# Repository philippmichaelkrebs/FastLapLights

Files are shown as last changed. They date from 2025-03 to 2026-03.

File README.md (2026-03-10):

# FastLapLights

**"Gentlemen, start your engines!"** 🏁  

Bring FIA-style lighting to your slot car track with FastLapLights - a high-tech lighting and telemetry system for Carrera Digital tracks! 
Control WS2812b Start Lights, Pit Lane Lights and Track Flags with stunning LED animations that bring your races to life. Want more? FastLapLights als taps into the real-time data stream from the Carrera Control Unit, filters the most relevant messages, and outputs the via UART - perfect for powering external displays, mechanical 7-segment scoring pylons, or even fuel and pit-stop management systems. 
With support for 3.3V and 5V output, you've got everything you need to bring custom hardware into the mix.
Whether you're racing for fun or building the ultimate home track, FastLapLights adds a whole new level of immersion, control and creativity.

Following Models are supported:
- Carrera Digital 124
- Carrera Digital 132

Preview:  
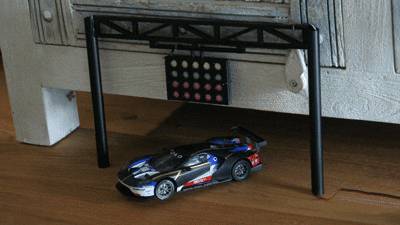
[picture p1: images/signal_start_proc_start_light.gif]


# Features

## Start Lights
Perfect race countdown sequence with WS2812B LEDs 🚦

You can switch between horizontal and vertical alignment for the start lights WS2812B led strips. Vertical alignment requires more soldering but looks more realistic, giving you the option to physically seperate the  lights - just like in real motorsport.
The system is designed to handle 40 leds. So both the front and the back of the lights illuminated. You nearly have a 360 degree visibility of the start lights.

## Pit Lane Lights
Manage pit stops like a real motorsport pro!

Instead of start loghts, you can choose to illuminate pit lane lights. This is an either-or option - controlled via a solder bridge on the back of the pcb. Simpy close the appropriate bridge to switch the functionality.

## Track Flag System
RGB LEDs indicate race conditions (Green, Yellow, Red) 🚥

With a red and green led, you can animate track lights. It's also possible to use a rgb led with r and g connected only. Race status indicated by flags:
- Green: go, 
- Yellow: caution, 
- Red: stop
If you plan to use multiple RGB LEDs, you should use a mosfet to avoid overloading the uCs GPIOs.

## Real-Time Data Capture
Tap into live control unit telemetry!

The STM32 continuously processes data from the Carrera Control Unit. A filtered stream of the most relevant messages is available via the UART interface. This gives you a powerful foundation to build custom applications and add unique behavior to your racetrack setup. 
Whether it's a mechanical 7-segment scoring pylon or a smart pit stop prediction system, FastLapLights gives your cicuit the edge it deserves.

# Get Started

- Order the microcontroller from jlcpcb (see section documentation)
- Flash the firmware on your STM32 microcontroller (see section documentation)
- Connect WS2812B & RGB LEDs according to the purpose.
- Solder power wires to the track
- Power up & lights out!

# Pinouts
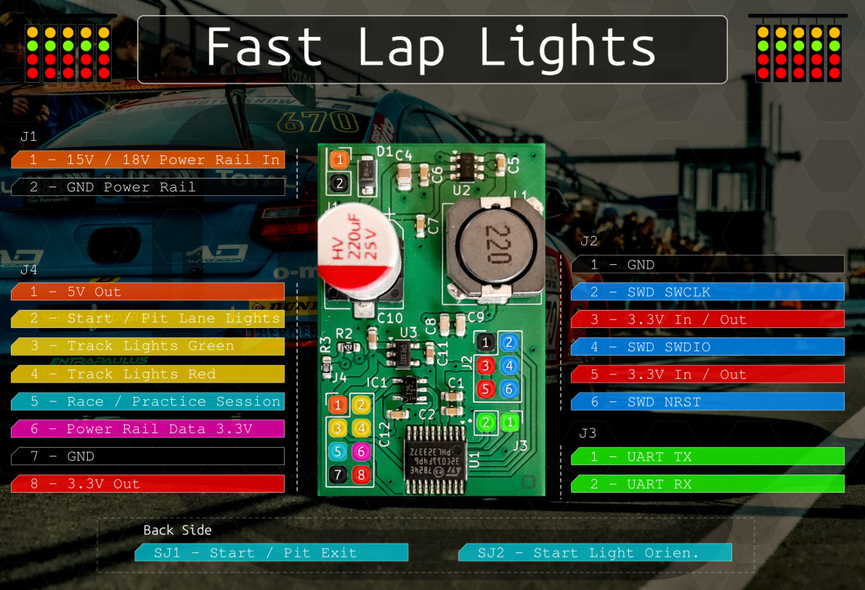
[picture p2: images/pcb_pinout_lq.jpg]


# UART
The data that is transmitted by the Control Unit is an asynchronous serial protocol. The chunks are of various size. Notably, the protocol doesn't use a traditional stop bit. The cu transmits data in a structured, continouos stream every 75 milli secs. Each transmission cycle contains 10 distinct messages sent in a strict and predictable sequence.

The controller processes this incomimg data and outputs it via UART, using a **32-byte single-buffered TX DMA system**. Each UART transmission contains a snapshot of the current race state. TX only, RX is disabled.

## UART Configuration
- Baud rate: 115200
- Data format: 8 data bits, no parity, 1 stop bit (8N1)
## Application Behavior
- Message Size: Each UART message is exactly 32 bytes in length.
- Contents: The message includes all relevant application data (e.g., race state, positions, fuel levels, etc.) and is a snapshot of the current race state.
- Transmission Rate: A new message is transmitted every 750 milliseconds.

|Byte Index|Field|Description|
|---|---|---|
|{0,4,...}|`Driver X - Fuel`|Remaining fuel of Driver 0–5|
|{1,5,...}|`Driver X - Position`|Current position of Driver 0–5|
|{2,6,...}|`Driver X - Finished`|Driver 0–5 has finished the race (1 = finished)|
|{3,7,...}|`Driver X - Laps`|Laps completed by Driver 0–5|
|24|`Fastest Lap`|Driver index with the fastest lap (0–5, or 0xFF if none)|
|25|`Start Lights Count`|Number of red lights currently lit|
|26|`Lap Count`|Total laps completed by the leader|
|27|`Reset Event`|Non-zero if a global reset has occurred|
|28|`Race State`|Current state of the race (see `RaceState` enum)|
|29|`Session Type`|Race or Qualifying session (see `SessionType` enum)|
|30 & 31|`Track Time`|16-bit track time counter, synced with track (13.33 Hz)|

## Message Decoding Example

The following C code snippet demonstrates how to decode the message and populate internal state structures:
```c 
typedef enum {
	RACE,
	QUALIFYING_TRAINING
}S essionType;

typedef enum {
	RACE_STATE_STARTUP,
	RACE_STATE_RED_FLAG,
	RACE_STATE_YELLOW_FLAG,
	RACE_STATE_GREEN_FLAG,
	RACE_STATE_START_PROC,
	RACE_STATE_JUMP_START,
	RACE_STATE_OPEN
} RaceState;

typedef struct {
	uint8_t fuel;
	uint8_t position;
	uint8_t finished;
	uint8_t laps;
} DriverData;

typedef struct {
	DriverData 	      driver_data[6];
	uint8_t		fastest_lap_driver;
	uint8_t		start_lights;
	uint8_t		lap_count;
	uint8_t		lap_count_nibble_completed;
	uint8_t		reset_event;
	RaceState	      race_state;
	SessionType	      session_type;
} RaceInfo;

// Global structure updated via UART
volatile RaceInfo	uart_race_info = {
		.driver_data = {
			{ .fuel = 0, .position = 0, .finished = 0, .laps = 0 },
			{ .fuel = 0, .position = 0, .finished = 0, .laps = 0 },
			{ .fuel = 0, .position = 0, .finished = 0, .laps = 0 },
			{ .fuel = 0, .position = 0, .finished = 0, .laps = 0 },
			{ .fuel = 0, .position = 0, .finished = 0, .laps = 0 },
			{ .fuel = 0, .position = 0, .finished = 0, .laps = 0 }
		},
		.fastest_lap_driver = 0xFF,       // 0xFF no fastest lap yet
		.start_lights = 0,
		.lap_count = 0,
		.reset_event = 0,
		.race_state = RACE_STATE_STARTUP,
		.session_type = RACE
	};
	
volatile uint8_t rx_buf[32];

void uart_interrupt(void){
	uint8_t buf_idx = 0;
	for (uint8_t _driver = 0; _driver < 6; _driver++){
		uart_race_info.driver_data[_driver].position = 
			rx_buf[buf_idx++];
		uart_race_info.driver_data[_driver].fuel = 
			rx_buf[buf_idx++];
		uart_race_info.driver_data[_driver].laps = 
			rx_buf[buf_idx++];
		uart_race_info.driver_data[_driver].finished = 
			rx_buf[buf_idx++];
	}

	uart_race_info.fastest_lap_driver = rx_buf[buf_idx++];
	uart_race_info.start_lights = rx_buf[buf_idx++];
	uart_race_info.lap_count = rx_buf[buf_idx++];
	uart_race_info.reset_event = rx_buf[buf_idx++];
	uart_race_info.race_state = (RaceState)rx_buf[buf_idx++];
	uart_race_info.session_type = (SessionType)rx_buf[buf_idx++];

	track_time = 0xFF00 & (rx_buf[buf_idx++] << 8);
	track_time |= rx_buf[buf_idx++];
}
```

# Documentation
- [How the Lights Work](/docs/how_the_lights_work.md)
- [Getting Started](/docs/getting_started.md)

# Contribute & Support

Got ideas? Found a bug? Want to make it even cooler? 
Open an issue, submit a PR, or just say hi!

Developer: Philipp Krebs  
Contact: pmge.krebs@gmail.com  
Repo: https://github.com/philippmichaelkrebs

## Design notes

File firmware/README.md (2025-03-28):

# Overview
The system decodes Manchester-encoded data from the power line and categorizes messages based on their content. Once a new message is available, it is stored in a FIFO buffer, and the interrupt pin is set HIGH. The I2C master can then request the stored data. The relevant messages occus at round about 13Hz.

# Data Handling & Communication
## Manchester Code Decoding
The system continuously decodes Manchester-encoded data from the track’s power line.
Messages are categorized into predefined patterns for easy processing.

## FIFO Buffer & Interrupts
New data is stored in a FIFO buffer. When new messages arrive, the interrupt pin is set HIGH to signal the presence of new data.
Via I2C request a message from the FIFO. The system responds with the latest available data. The interrupt pin is cleared once the FIFO is read.

# Data Message Structure
Each data chunk is 16 bits (2 bytes) long and consists of an identifier and a value:
Bits    Field   Description
15-8    Identifier  Defines the type of message (e.g., car status, system events)
7-0 Value   Stores specific data related to the identifier (e.g., speed, lap time)

## Message Types & Decoding

The identifier (high byte) determines the type of data, while the value (low byte) contains specific information.
### Car-Related Messages
| Identifier (Hex)  | Description |
|---:|-----|
| 0xFF0Z |  Car with ID Z finishes the race |
| 0xFEXZ |  Car with ID Z crosses the lap counter; if X = 1, it records a new fastest lap |
| 0xFDXZ |  Speed of car Z, where Z is a 4-bit car ID, and X is a 12-bit speed value |
| 0xFCXZ |  Fuel level of car Z (X is a 3-bit integer fuel value) |
| 0xFBXZ |  Throttle position of car Z |
| 0xFA0Z |  Car Z jumped the start |
### System Messages
| Identifier (Hex)  | Description |
|---:|-----|
| 0xAA0X |  Number of start lights illuminated (X = 0 to 5) |
| 0xAB0X | Yellow flag (X = 1 yellow flag, X = 0 yellow flag withdrawn |
| 0x0001 |  Total system reset |
| 0x0002 |  Reset position and lap counter |

## Example Data Transactions
### Example 1: Car 3 Finishes the Race
Raw Message: 0xFF03
Decoded:

    Identifier: 0xFF → Car finishes race. 
    Car ID: 03 
    Description: Car 3 finished the race.

### Example 2: Start lights changed
Raw Message: 0xAA03
Decoded:
    
    Identifier: 0xAA → Start lights changed
    Value: 3
    3 red lights lit at the start light

# Notes & Considerations
The interrupt pin remains HIGH until the FIFO is read.

# Contribute & Support

Got ideas? Found a bug? Want to make it even cooler? 
Open an issue, submit a PR, or just say hi!

    Developer: Philipp Krebs 
    Contact: pmge.krebs@gmail.com 
    Repo: https://github.com/philippmichaelkrebs

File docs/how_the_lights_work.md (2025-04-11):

# 🏁 How the Lights Work

## 📘 Introduction to FIA Light Signals

The FIA (Fédération Internationale de l'Automobile) defines several key light systems in their [recommendations for motor racing](https://argent.fia.com/web/fia-public.nsf/1330F0769A59327AC125736200478FB9/$FILE/03__Recommended_light_signals.pdf). These signals help ensure safety and structure during a race. Here's a simplified breakdown:

- **Start Light System**
  - Indicates the track status: open, closed, or released
  - Controls the start procedure
  - Signals a jump start or aborted start

- **Pit Lane Lights**
  - Indicates whether the pit lane is open or closed

- **Track Light Signals**
  - **Yellow flag**: caution, danger ahead
  - **Red flag**: race is stopped or paused
  - **Green flag**: track is clear and race continues

These are the most relevant signals for our slot car adaptation.

---

## 🟥 Red Flag – Race Pause

In FIA terms, a red flag means race stoppage. For us slot car/Carrera fans, it’s more like a **race pause**. All cars stop immediately — often because a car flies off the track and needs rescue. This can happen:

- **Before the start procedure begins**, or
- **Mid-race**, due to track incidents

The control unit sends a **reset** followed by a **5x red light** signal. If the previous state wasn't a start sequence, it's treated as a red flag.

### Light Behavior

- **Start Light**: All red lights ON. Yellow and green OFF.  
- **Pit Lane**: Red light ON – pit lane is closed.  
- **Track Lights**: All lights RED – red flag signal.

### How The Start Light Looks
 


### How The Track Light Looks
 


---

## 🟨 Yellow Flag / Safety Car Phase

A yellow flag indicates caution on the track – there's an incident or obstacle. You can optionally deploy a **safety car**. Without one, drivers are simply advised to slow down (though that's more a gentleman’s agreement than a rule 😉).

You trigger this phase by pressing the **Safety Car button**.

### Light Behavior

- **Start Light**: Yellow lights BLINK at 5 Hz.  
- **Pit Lane**: Green light ON – pit lane is open.  
- **Track Lights**: Yellow lights BLINK at 5 Hz.

### How The Start Light Looks
 


### How The Track Light Looks
 


---

## 🟩 Green Flag – Race Resumes

A green flag means the track is clear and the race is back on.

There’s **no direct button** to start a green flag phase. Instead, it's shown **automatically for 10 seconds** after ending a red flag or yellow flag phase.

### Light Behavior

- **Start Light**: Green lights BLINK at 1 Hz (for 10 seconds).  
- **Pit Lane**: Green light ON – track and pit lane are open.  
- **Track Lights**: Green lights BLINK at 1 Hz – track is clear.

---

## 🚦 Start Procedure

Pressing the **Start button** during a red flag triggers the official **start sequence**. According to FIA rules, only the **start light system** is active during this sequence — track lights remain off, assuming the track is already clear.

### Light Behavior

- **Start Light**: Red lights turn on in sequence (typical countdown).  
- **Pit Lane**: Red light ON during countdown; turns green at race start.  
- **Track Lights**: All OFF – the track is considered ready.

### How The Start Light Looks
 


---

## 🚫 Jump Start

If a car jumps the start by hitting the throttle before the lights go out, it’s a **jump start**. In slot car logic, this acts like a **start abort**. So we follow the FIA approach:

### Light Behavior

- **Start Light**: Red lights stay ON; Yellow lights FLASH at 1 Hz.  
- **Pit Lane**: Red light ON – pit lane closed.  
- **Track Lights**: All OFF – track assumed clear.

### How The Start Light Looks
 


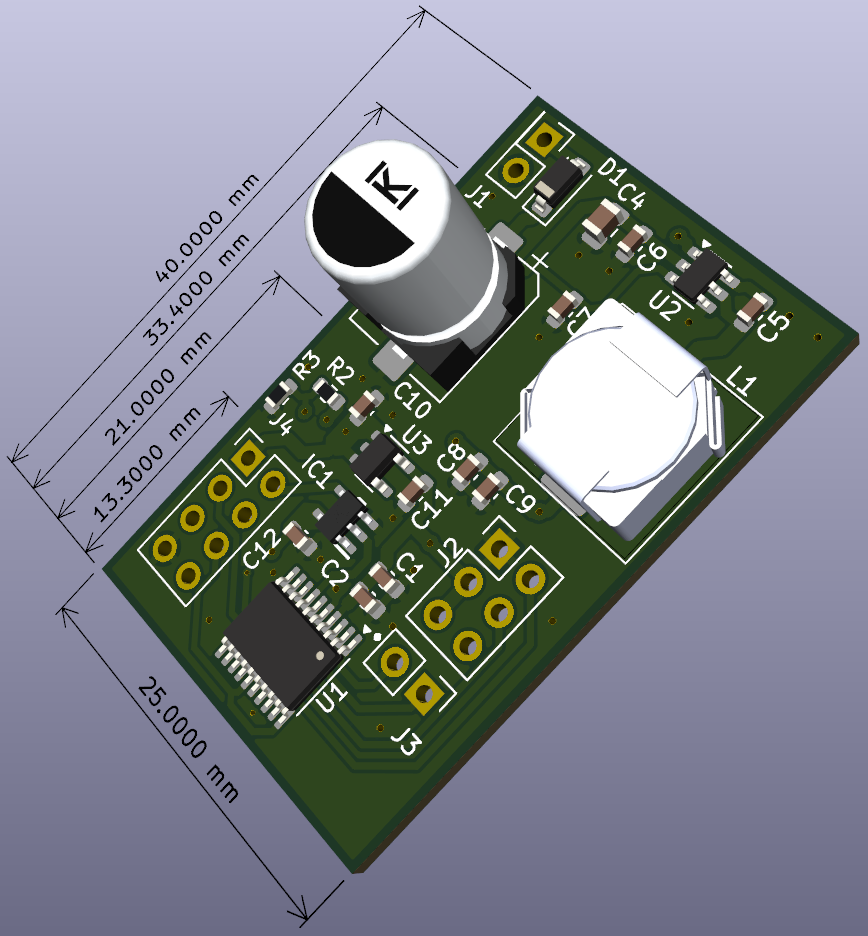
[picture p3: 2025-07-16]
images/FastLapLightsMK7.png

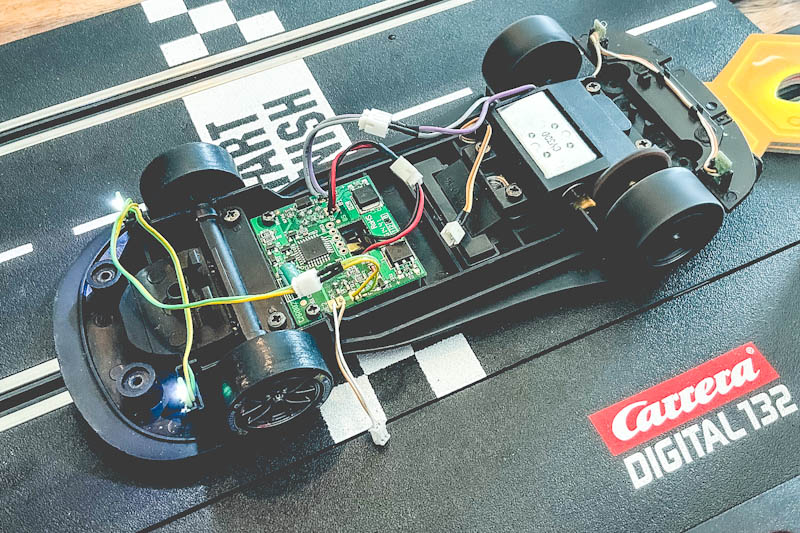
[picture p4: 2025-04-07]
images/protocol_reverse_engineering.jpg

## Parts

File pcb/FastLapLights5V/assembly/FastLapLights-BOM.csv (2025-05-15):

Designator | Comment | Footprint | LCSC
C1,C10,C11 | 4.7uF | Capacitor_SMD:C_0603_1608Metric | C1705
C2,C5,C6,C7,C12 | 0.1uF | Capacitor_SMD:C_0603_1608Metric | C1591
C3 | 220uF | Library:CP_220_Honor_Elec_HV1E227M0810PZ | C5246542
C4 | 22uF | Capacitor_SMD:C_0805_2012Metric | C602037
C8,C9 | 22uF | Capacitor_SMD:C_0603_1608Metric | C86295
D1 | MBR0540 | Diode_SMD:D_SOD-123 | C236080
IC1 | 74HCT1G125GV,125 | Library:SOT95P275X110-5N | C12502
L1 | 22uH | Library:L_SXN_SMDRH104R-220MT | C72414
R2 | 4k7 | Resistor_SMD:R_0603_1608Metric | C99782
R3 | 1k | Resistor_SMD:R_0603_1608Metric | C22548
U1 | STM32C011F4Px | Package_SO:TSSOP-20_4.4x6.5mm_P0.65mm | C5452432
U2 | AP63205WU | Package_TO_SOT_SMD:TSOT-23-6 | C2071056
U3 | AP2112K-3.3 | Package_TO_SOT_SMD:SOT-23-5 | C3021085

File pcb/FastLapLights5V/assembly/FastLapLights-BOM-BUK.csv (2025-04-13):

Designator | Comment | Footprint | LCSC
C1 | 4.7uF | Capacitor_SMD:C_0603_1608Metric | C1705
C2 | 0.1uF | Capacitor_SMD:C_0603_1608Metric | C1591
C3 | 100uF | Library:CP_Elec_A768KS227M1VLAE024 | C3274444
C4 | 22uF | Capacitor_SMD:C_0805_2012Metric | C602037
C5 | 100nF | Capacitor_SMD:C_0805_2012Metric | C519981
C6 | 0.1uF | Capacitor_SMD:C_0805_2012Metric | C519981
C7 | 4.7uF | Capacitor_SMD:C_0603_1608Metric | C1705
C8 | 4.7uF | Capacitor_SMD:C_0603_1608Metric | C1705
C9 | 0.1uF | Capacitor_SMD:C_0805_2012Metric | C519981
C10 | 22uF | Capacitor_SMD:C_0603_1608Metric | C86295
C11 | 22uF | Capacitor_SMD:C_0603_1608Metric | C86295
C12 | 0.1uF | Capacitor_SMD:C_0805_2012Metric | C519981
C13 | 22uF | Capacitor_SMD:C_0603_1608Metric | C86295
C14 | 0.1uF | Capacitor_SMD:C_0603_1608Metric | C1591
D1 | MBR0540 | Diode_SMD:D_SOD-123 | C236080
IC1 | 74HCT1G125GV,125 | Library:SOT95P275X110-5N | C12502
L1 | 22.8uH | Library:L_EATON_DR1030-220-R | C2638823
R1 | 4k7 | Resistor_SMD:R_0603_1608Metric | C99782
R2 | 4k7 | Resistor_SMD:R_0603_1608Metric | C99782
R3 | 1k | Resistor_SMD:R_0603_1608Metric | C22548
U1 | STM32C011F4Px | Package_SO:TSSOP-20_4.4x6.5mm_P0.65mm | C5452432
U2 | AP63205WU | Package_TO_SOT_SMD:TSOT-23-6 | C2071056
U3 | AP2112K-3.3 | Package_TO_SOT_SMD:SOT-23-5 | C51118
U4 | BD33FC0FP | Package_TO_SOT_SMD:TO-252-2 | C2846670

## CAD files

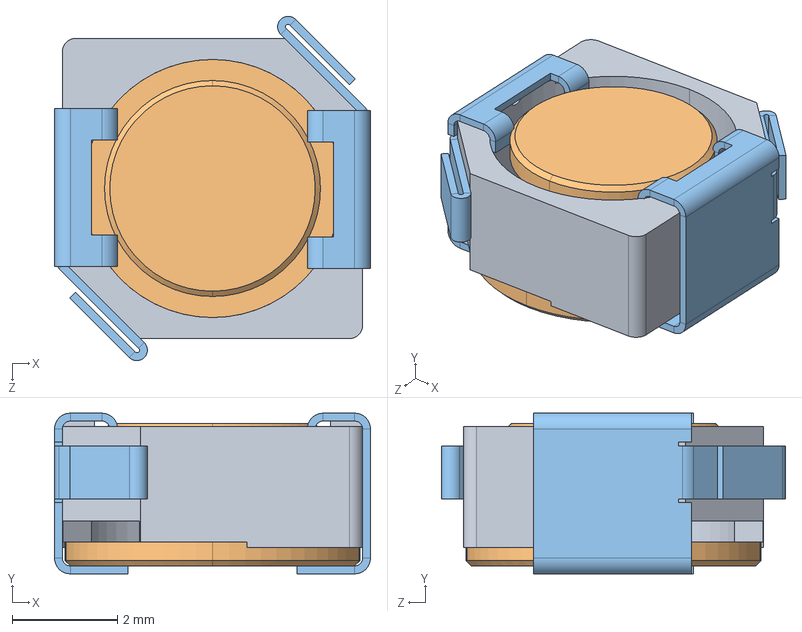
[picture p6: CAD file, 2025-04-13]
pcb/FastLapLights5V/3D/DR1030-220-R.stp
6.00 x 3.05 x 6.54 mm

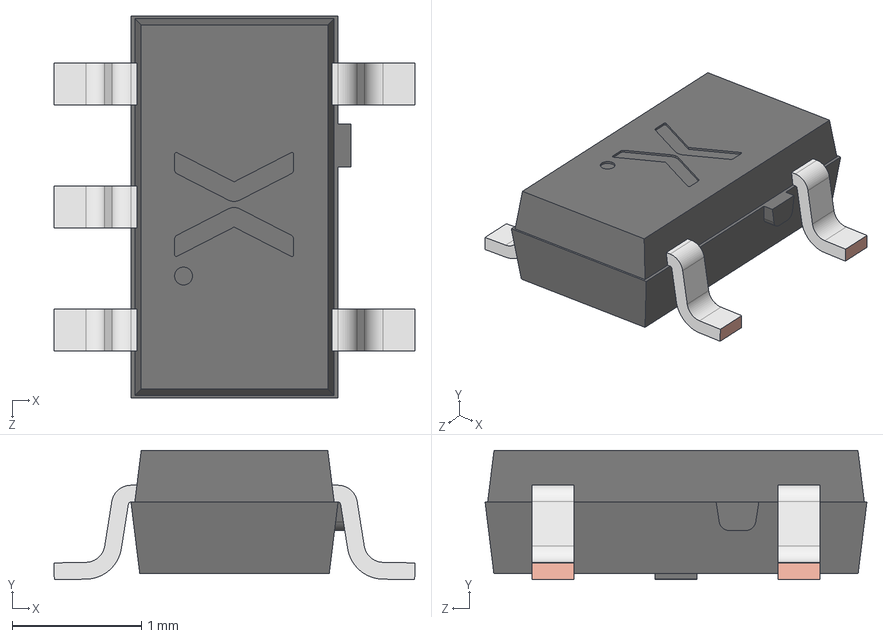
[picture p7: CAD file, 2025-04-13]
pcb/FastLapLights5V/3D/74HCT1G125GV,125.stp
2.79 x 1.00 x 2.95 mm
SOT753 Lower mold body
SOT753 Lead x 5
SOT753 Upper mold body

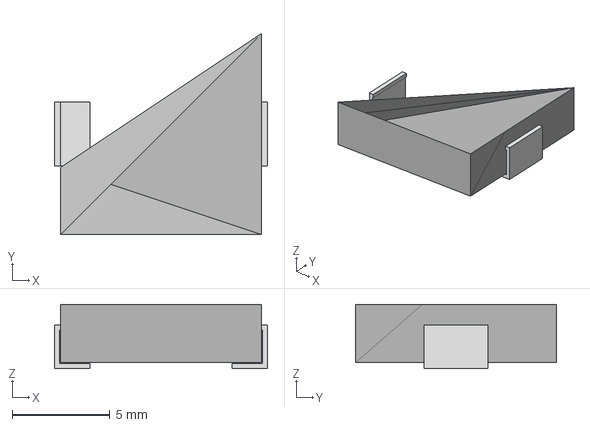
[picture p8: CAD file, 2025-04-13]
pcb/FastLapLights5V/3D/DR1030.step
10.9 x 10.3 x 3.30 mm

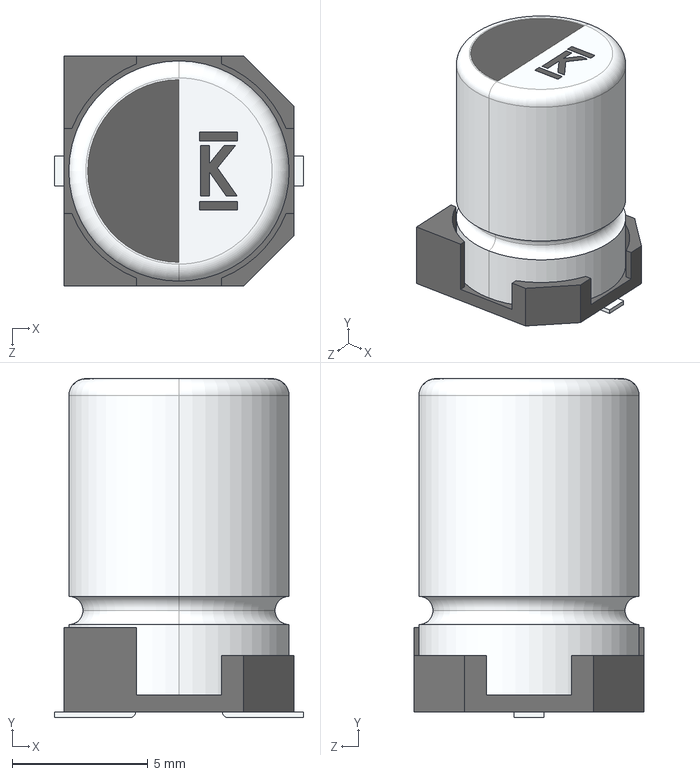
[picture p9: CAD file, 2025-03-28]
pcb/FastLapLights5V/3D/A768KS227M1VLAE024.step
9.20 x 12.5 x 8.50 mm

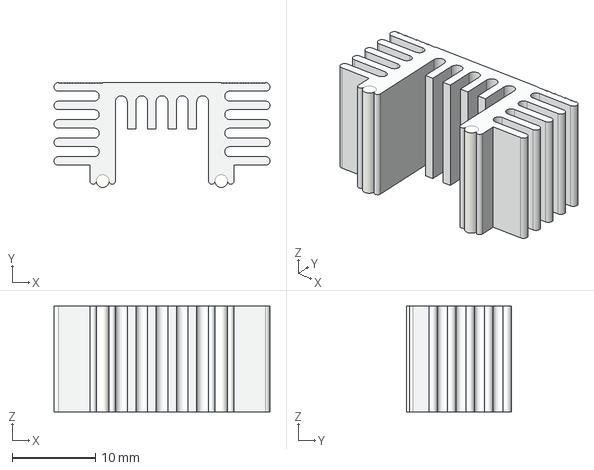
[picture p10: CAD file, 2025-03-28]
pcb/FastLapLights5V/3D/DV-T263-201E-TR.stp
25.9 x 12.6 x 12.7 mm

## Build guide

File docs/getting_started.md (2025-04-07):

# 🏎️ FastLapLight – FIA Style Lights for Slot Car Racing

Bring high-speed realism to your slot car track with FastLapLight – a customizable lighting system that emulates real FIA race lights for start sequences, pit lane, and track sectors.

## What You Need

    - Access to this repository
    - PCB from JLCPCB (with assembly option)
    - WS2812B LED strip (60 LEDs/m)
    - 5mm RGB LEDs (for track lights)
    - 3D printer for enclosures (STL files included)
    - Basic soldering tools and wire

## Step-by-Step Setup
### 1. Clone the Repo via: 
 
git clone https://github.com/philippmichaelkrebs/FastLapLights.git

    - Make sure to clone all files, including the STL and assembly folders.
    - Alternativly download the repository as zip.

### 2. Order PCB from JLCPCB

- Go to jlcpcb.com
- Upload the Gerber files located in the /pcb folder
- Select Assembly option
- Upload the required BOM and Pick & Place files from /assembly

Once the PCB arrives, all surface-mounted components will already be placed for you.

### 3. Print the Enclosures

    Navigate to the STL/ folder

    Choose the appropriate housing:
    
        - generic_light_base.stl
        - starting_light_jib.stl
        - starting_light_faceplate.stl
        - pit_lane_light.stl

    Use your favorite slicer and print using black PLA or ABS for best realism

### 4. Choose Your Light Setup

 | Light Type   | LED Type |    LED Count |
 | -------------|----------|--------------|
|Starting Light |WS2812B (60/m)|    40 LEDs|
|Pit Lane Light |WS2812B (60/m) | 12 LEDs|
|Track Sector   |5mm RGB LEDs   | As needed|

    - Cut the WS2812B strip to the appropriate lengths
    - For track lights, solder your own 5mm RGB LEDs directly to the PCB

### 5. Solder & Assemble

Once your PCB arrives:

    - Solder pin headers or wires as needed
    - Connect the WS2812B strips to the correct pads
    - Use 2 wires to connect the light system to your slot car track (power and signal)

Make sure the polarity and orientation match your layout!

## 🚦 Light Modes (Optional Preview)

    FIA-accurate start sequence
    Pit lane entry/exit animations
    Yellow/Green/Red flag logic
    DMA-driven WS2812B control

## Coming Soon

    - Full firmware flashing guide
    - Full hardware wirering and soldering guide

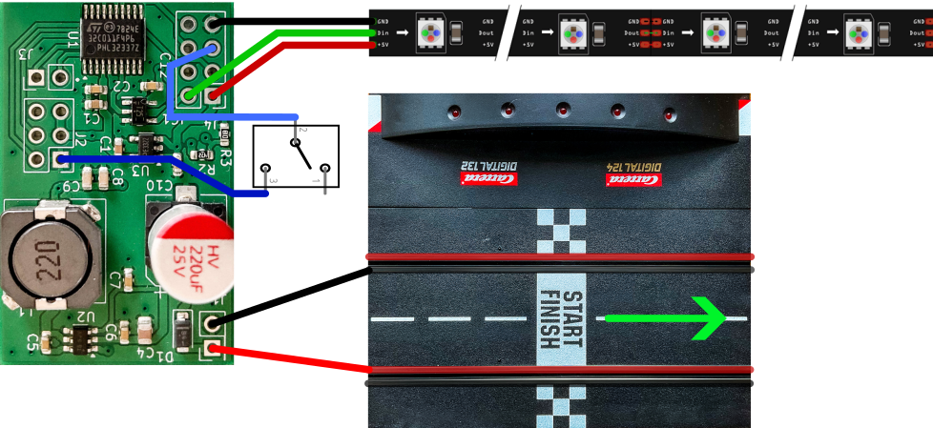
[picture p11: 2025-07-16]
images/wiring_pcb.png

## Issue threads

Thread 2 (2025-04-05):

add i2c

philippmichaelkrebs, 2025-04-05:
after having huge trouble with dma (pwm start dma), I first have to test the implementation very well.

Closed 2025-07-04.

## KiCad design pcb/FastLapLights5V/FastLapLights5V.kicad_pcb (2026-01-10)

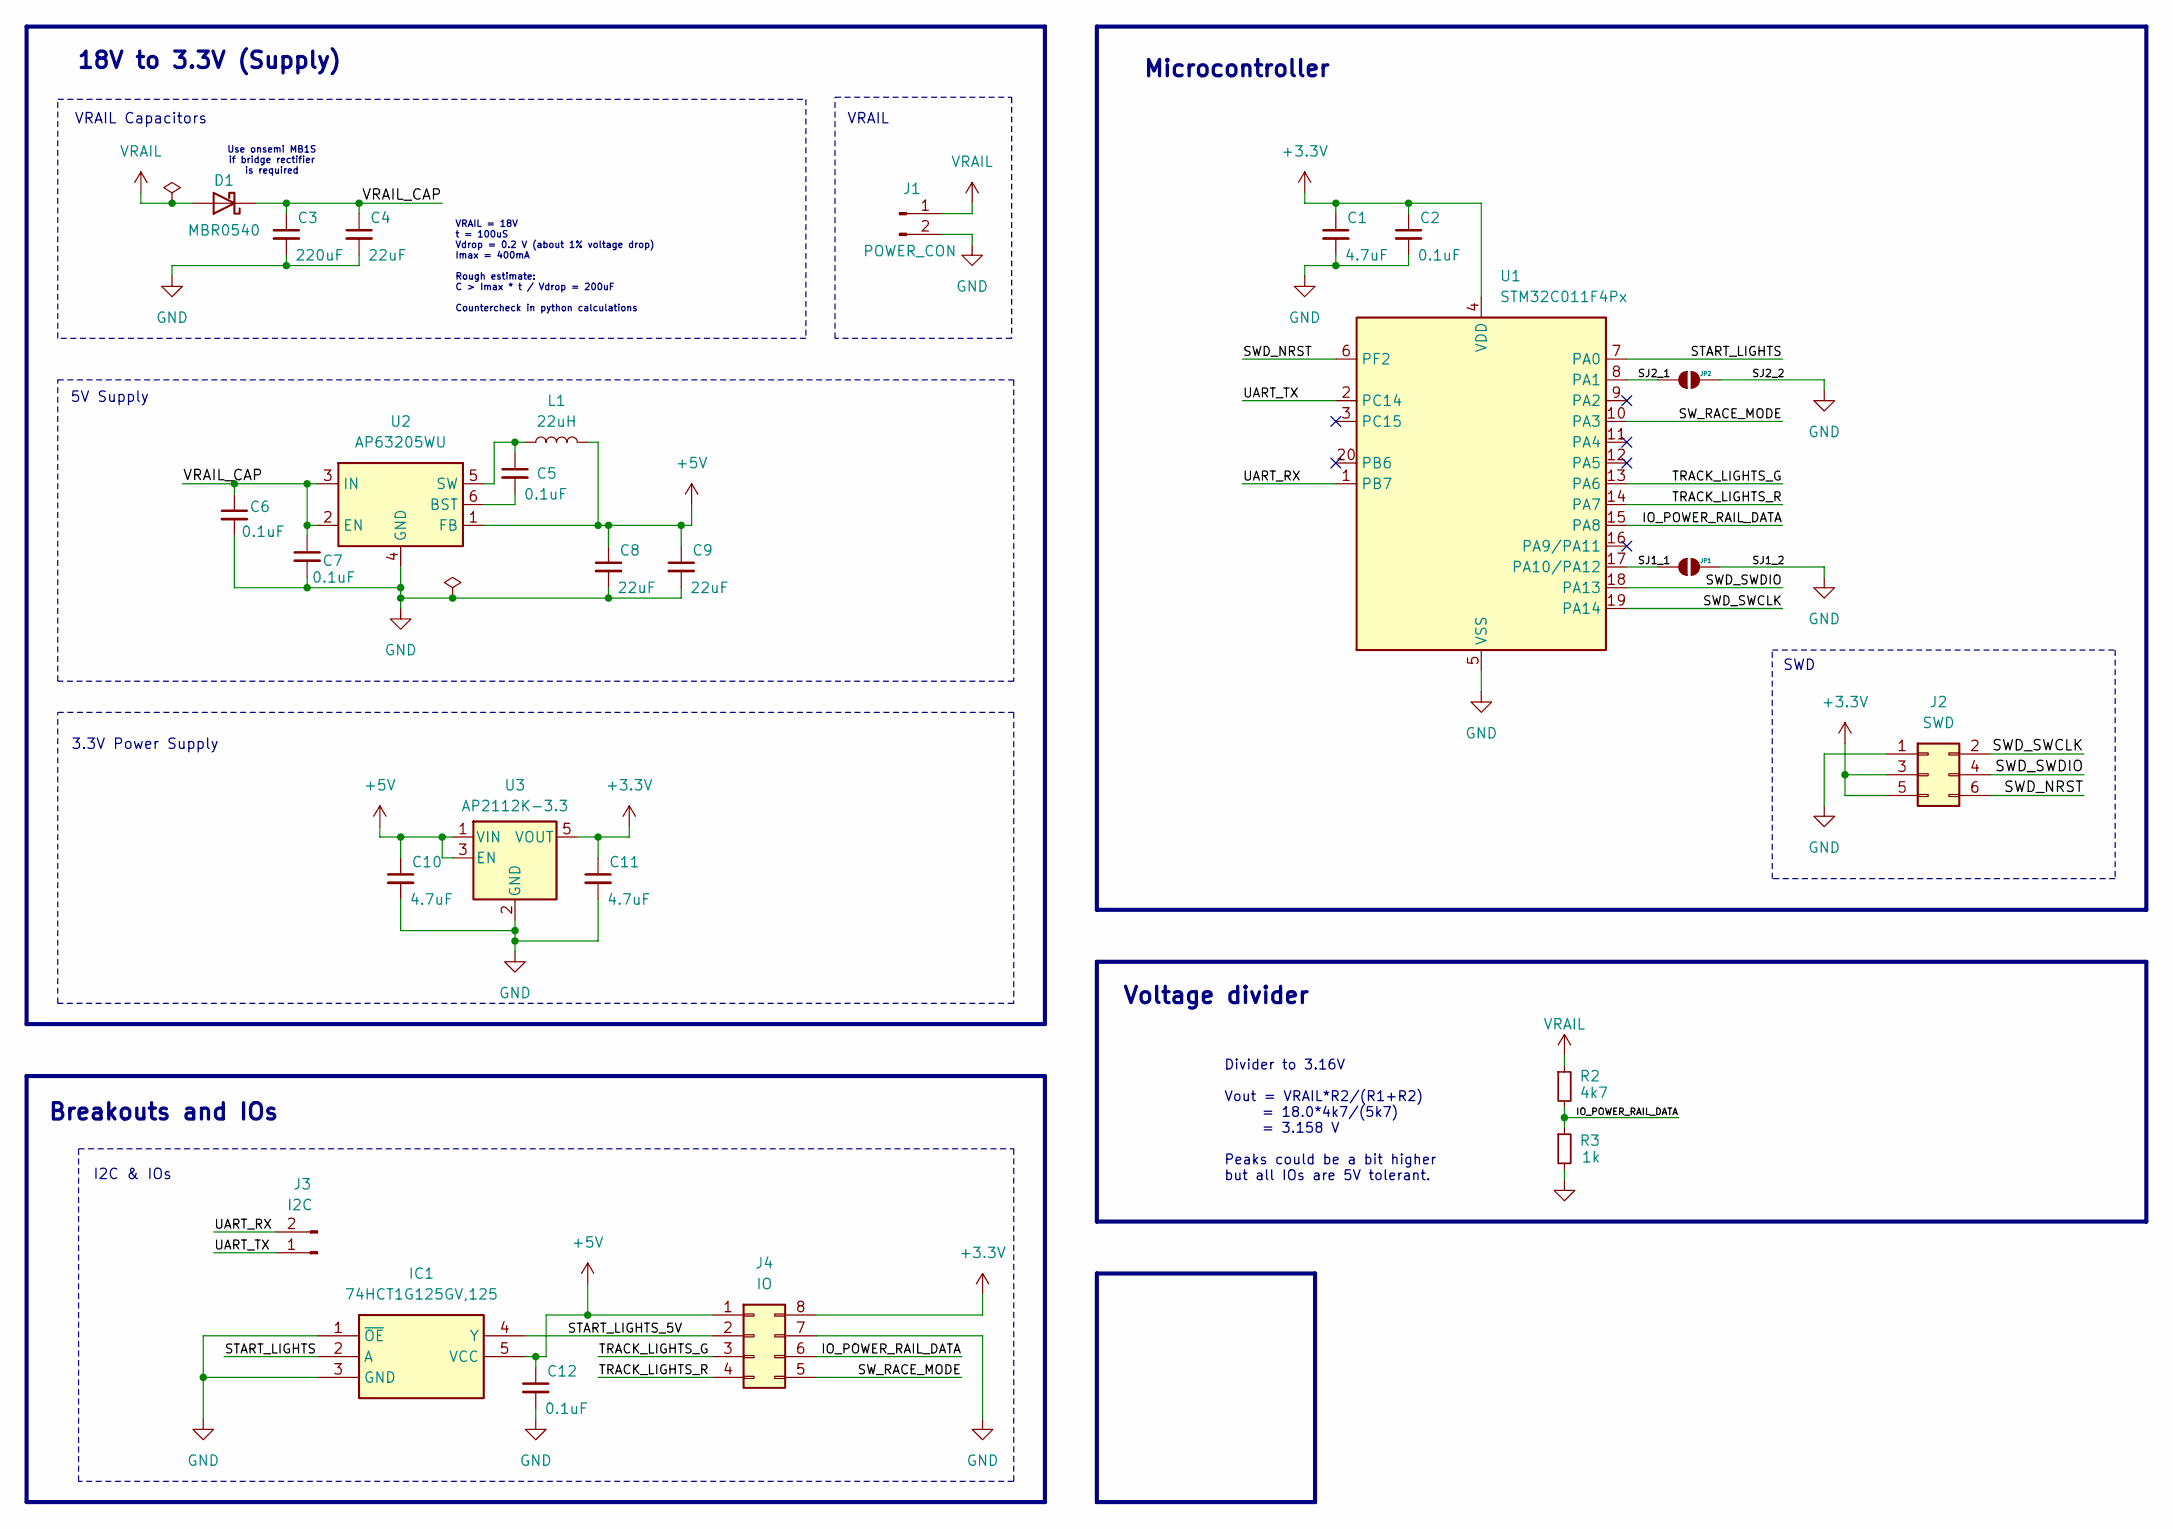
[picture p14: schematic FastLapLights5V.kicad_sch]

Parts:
C1, C10, C11: 4.7uF; C_0603_1608Metric; LCSC C1705
C2, C5, C6, C7, C12: 0.1uF; C_0603_1608Metric; LCSC C1591
C3: 220uF; CP_220_Honor_Elec_HV1E227M0810PZ; LCSC C5246542
C4: 22uF; C_0805_2012Metric; LCSC C602037
C8, C9: 22uF; C_0603_1608Metric; LCSC C86295
D1: MBR0540; D_SOD-123; LCSC C236080
IC1: 74HCT1G125GV,125; SOT95P275X110-5N; Mouser Part Number 771-74HCT1G125GV
J1: POWER_CON; PinHeader_2x01_P2.54mm_Vertical
J2: SWD; PinHeader_2x03_P2.54mm_Vertical
J3: I2C; PinHeader_1x02_P2.54mm_Vertical
J4: IO; PinHeader_2x04_P2.54mm_Vertical
JP1, JP2: SP; SolderJumper-2_P1.3mm_Open_RoundedPad1.0x1.5mm
L1: 22uH; L_SXN_SMDRH104R-220MT; LCSC C72414
R2: 4k7; R_0603_1608Metric; LCSC C99782
R3: 1k; R_0603_1608Metric; LCSC C22548
U1: STM32C011F4Px; TSSOP-20_4.4x6.5mm_P0.65mm; LCSC C5452432
U2: AP63205WU; TSOT-23-6; LCSC C2071056
U3: AP2112K-3.3; SOT-23-5; LCSC C3021085

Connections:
+3.3V: C1.1, C2.1, C11.1, J2.3, J2.5, J4.8, U1.4 (VDD), U3.5 (VOUT)
+5V: C8.1, C9.1, C10.1, C12.1, IC1.5 (VCC), J4.1, L1.2, U2.1 (FB), U3.1 (VIN), U3.3 (EN)
/IO_POWER_RAIL_DATA: J4.6, R2.2, R3.1, U1.15 (PA8)
/SJ1_1: JP1.1 (A), U1.17 (PA10/PA12)
/SJ2_1: JP2.1 (A), U1.8 (PA1)
/START_LIGHTS: IC1.2 (A), U1.7 (PA0)
/START_LIGHTS_5V: IC1.4 (Y), J4.2
/SWD_NRST: J2.6, U1.6 (PF2)
/SWD_SWCLK: J2.2, U1.19 (PA14)
/SWD_SWDIO: J2.4, U1.18 (PA13)
/SW_RACE_MODE: J4.5, U1.10 (PA3)
/TRACK_LIGHTS_G: J4.3, U1.13 (PA6)
/TRACK_LIGHTS_R: J4.4, U1.14 (PA7)
/UART_RX: J3.2, U1.1 (PB7)
/UART_TX: J3.1, U1.2 (PC14)
/VRAIL_CAP: C3.1, C4.1, C6.1, C7.1, D1.1 (K), U2.2 (EN), U2.3 (IN)
GND: C1.2, C2.2, C3.2, C4.2, C6.2, C7.2, C8.2, C9.2, C10.2, C11.2, C12.2, IC1.1 (~OE), IC1.3 (GND), J1.2, J2.1, J4.7, JP1.2 (B), JP2.2 (B), R3.2, U1.5 (VSS), U2.4 (GND), U3.2 (GND)
unnamed: C5.2, U2.6 (BST)
unnamed: C5.1, L1.1, U2.5 (SW)
VRAIL: D1.2 (A), J1.1, R2.1

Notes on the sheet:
3.3V Power Supply
Use onsemi MB1S if bridge rectifier is required
5V Supply
Voltage divider
Breakouts and IOs
Microcontroller
Divider to 3.16V Vout = VRAIL*R2/(R1+R2) = 18.0*4k7/(5k7) = 3.158 V Peaks could be a bit higher but all IOs are 5V tolerant.
VRAIL = 18V t = 100uS Vdrop = 0.2 V (about 1% voltage drop) Imax = 400mA Rough estimate: C > Imax * t / Vdrop = 200uF Countercheck in python calculations
VRAIL
SWD
VRAIL Capacitors
I2C & IOs
18V to 3.3V (Supply)

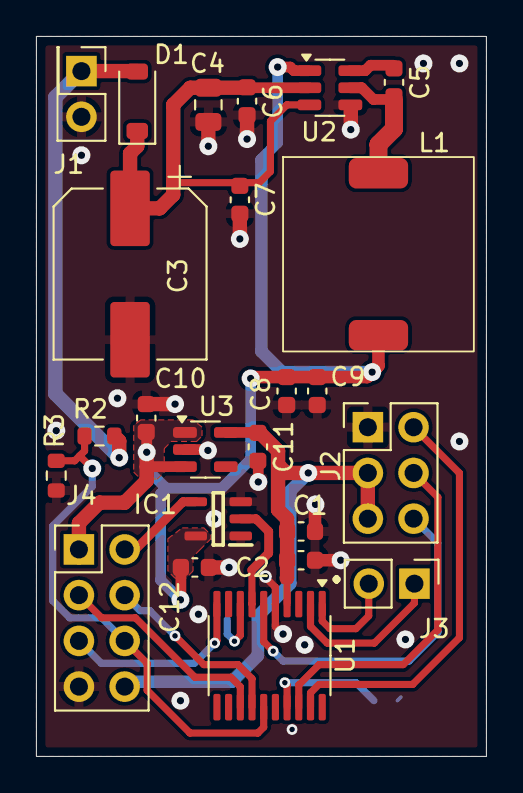
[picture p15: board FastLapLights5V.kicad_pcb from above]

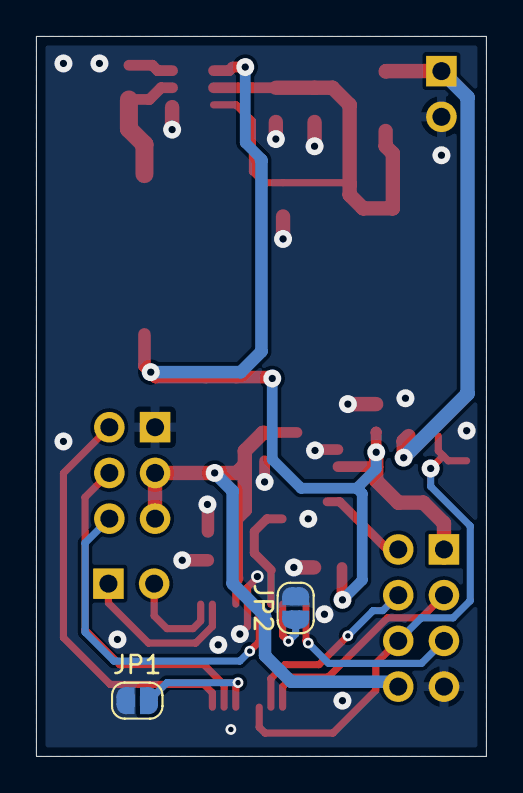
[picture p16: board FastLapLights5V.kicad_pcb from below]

Board: 4 copper layers, 25.0 x 40.0 mm, 26 parts (2 on the bottom side), 20 nets.

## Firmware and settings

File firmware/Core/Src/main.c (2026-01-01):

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
/* Includes ------------------------------------------------------------------*/
#include "main.h"

/* USER CODE BEGIN Includes */
#include "track_data_decoder.h"
#include "ws2812b_start_lights.h"
/* USER CODE END Includes */

/* USER CODE BEGIN PTD */
typedef enum {
	START_LIGHT_MODE,
	PIT_LANE_LIGHT_MODE
} LightMode;

typedef enum {
	ALIGNMENT_VERTICAL,
	ALIGNMENT_HORIZONTAL
}StartLightAlignment;

typedef enum {
	RACE,
	QUALIFYING_TRAINING
}SessionType;

typedef enum {
	RACE_STATE_STARTUP,
	RACE_STATE_RED_FLAG,
	RACE_STATE_YELLOW_FLAG,
	RACE_STATE_GREEN_FLAG,
	RACE_STATE_START_PROC,
	RACE_STATE_JUMP_START,
	RACE_STATE_OPEN
} RaceState;

typedef enum {
	UART_TX_BUFFER_FULL,
	UART_TX_BUFFER_TIMEOUT,
	UART_TX_FORCE
} UartTxTransmitReason;

typedef struct {
	RaceState curr;
	RaceState prev;
} RaceStateHistory;

typedef struct {
	uint8_t red_count; 			// 0 - 5
	uint8_t red_count_prev;
	uint8_t yellow_flag; 		// 0 - 1
	uint8_t yellow_flag_prev;
	uint8_t green_flag; 		// 0 - 1
	uint8_t green_flag_prev;
	uint8_t update_flag;
} StartLightValue;

typedef struct {
	uint16_t message_started;
	uint16_t start_time;
	uint16_t gap;
	uint16_t last_rising;
	uint16_t last_falling;
	uint16_t first_rising;
	uint16_t data;
} ManchesterDecoder;

typedef struct {
	uint8_t fuel;
	uint8_t position;
	uint8_t finished;
	uint8_t laps;
} DriverData;

typedef struct {
	DriverData 	driver_data[6];
	uint8_t		fastest_lap_driver;
	uint8_t		start_lights;
	uint8_t		lap_count;
	uint8_t		lap_count_nibble_completed;
	uint8_t		reset_event;
	RaceState	race_state;
	SessionType	session_type;
} RaceInfo;

/* USER CODE END PTD */

/* USER CODE BEGIN PD */
#define CIRC_BUF_LEN       	8U
#define UART_TX_BUF_LEN		(32U) //32U

#define HALF_BIT_TICKS   32
#define FULL_BIT_TICKS   64
#define GAP_THRESHOLD    132   // consider 160 as safer midpoint
#define GLITCH_FILTER    10    // ignore pulses shorter than ~16 µs
/* USER CODE END PD */


TIM_HandleTypeDef htim16;
DMA_HandleTypeDef hdma_tim16_ch1;

/* USER CODE BEGIN PV */
uint32_t 			track_counter = 0;
uint32_t 			millis_sync_prev = 0;
uint16_t 			millis_sync_state_change_flag = 0;

// manchester decoder
volatile ManchesterDecoder 	data_manchester[CIRC_BUF_LEN] = {0};
volatile uint16_t 			data_manchester_circular_index = 0;
volatile uint16_t 			data_manchester_circular_read_index = 0;
uint16_t 					difference_rw = 0;
volatile uint16_t 			track_data_available = 0;
uint16_t 					message_to_proceed = 0;
uint16_t					last_edge = 0;

// race state
RaceStateHistory 	race_state = {RACE_STATE_STARTUP, RACE_STATE_STARTUP};
StartLightValue 	start_light_value = {0};
uint8_t 			safetycar_debounce = 0; // neccessary because of ghost car messages
uint32_t 			green_flag_triggered_time = 0;
uint32_t 			safetycar_flash_interval = 0;
uint32_t 			green_flag_millis_flash = 0;
uint32_t 			jump_start_millis_flash = 0;

LightMode 			light_mode = START_LIGHT_MODE;
StartLightAlignment start_light_alignment = ALIGNMENT_HORIZONTAL;
SessionType 		session_type = RACE;
uint32_t 			start_light_change_time = 0;
HAL_StatusTypeDef 	dma_status_pwm = HAL_OK;

// driver data
DriverData			driver_data[6]								= {0};

// uart
static 	 uint8_t	uart_tx_buffer[UART_TX_BUF_LEN] 			;
uint32_t 			uart_tx_last_transmit						= 0;
/*
 * 0x01 - race state
 * 0x02 - driver data (fuel, laps, position)
 * 0x04 - start lights
 * 0x08 - reset
 * 0x10 - race finished
 * 0x20 - new fastest lap
 * 0x40 - session type (race, practice)
 */

volatile RaceInfo	uart_race_info = {
		.driver_data = {
				{ .fuel = 0, .position = 0, .finished = 0, .laps = 0 },
				{ .fuel = 0, .position = 0, .finished = 0, .laps = 0 },
				{ .fuel = 0, .position = 0, .finished = 0, .laps = 0 },
				{ .fuel = 0, .position = 0, .finished = 0, .laps = 0 },
				{ .fuel = 0, .position = 0, .finished = 0, .laps = 0 },
				{ .fuel = 0, .position = 0, .finished = 0, .laps = 0 }
		},
		.fastest_lap_driver = 0xFF,       // 0xFF no fastest lap yet
		.start_lights = 0,
		.lap_count = 0,
		.lap_count_nibble_completed = 1,
		.reset_event = 0,
		.race_state = RACE_STATE_STARTUP,
		.session_type = RACE
};

volatile uint16_t 	difference_channel2 = 0;
volatile uint16_t 	last_rising = 0;
/* USER CODE END PV */

void SystemClock_Config(void);
static void MX_GPIO_Init(void);
static void MX_DMA_Init(void);
static void MX_TIM3_Init(void);
static void MX_TIM14_Init(void);
static void MX_TIM16_Init(void);
static void MX_USART1_UART_Init(void);
/* USER CODE BEGIN PFP */
CuMessage decode_manchester(uint16_t message);
void track_data_callback(uint16_t capture, uint8_t direction);
void (*ptr_man_capture_isr)(uint16_t capture, uint8_t direction) = 0;
/* USER CODE END PFP */

/* USER CODE BEGIN 0 */

/*
 * circular buffer methods - manchester decoder
 */

/*static inline uint16_t circ_index(uint16_t i) {
	return i % CIRC_BUF_LEN;
}*/

static inline uint16_t circ_next(uint16_t i) {
	return (i + 1) & 0x0007; //% CIRC_BUF_LEN;
}

/*static inline uint16_t circ_prev(uint16_t i) {
	return (i + CIRC_BUF_LEN - 1) % CIRC_BUF_LEN;
}*/

static inline uint16_t circ_distance(uint16_t from, uint16_t to) {
	return (to >= from) ? (to - from) : (CIRC_BUF_LEN - from + to);
}

static inline void update_race_state(RaceStateHistory *stateHistory, RaceState newState) {
	stateHistory->prev = stateHistory->curr;
	stateHistory->curr = newState;
	uart_race_info.race_state = newState;
}

/*
 * update functions
 */

static inline void update_start_light_value_red(StartLightValue *startLightValue, uint8_t newValue) {
	startLightValue->red_count_prev = startLightValue->red_count;
	startLightValue->red_count = newValue;
	startLightValue->update_flag = 1;
	uart_race_info.start_lights = newValue;
}
static inline void update_start_light_value_green(StartLightValue *startLightValue, uint8_t newValue) {
	startLightValue->green_flag_prev = startLightValue->green_flag;
	startLightValue->green_flag = newValue;
	startLightValue->update_flag = 1;
}
static inline void update_start_light_value_yellow(StartLightValue *startLightValue, uint8_t newValue) {
	startLightValue->yellow_flag_prev = startLightValue->yellow_flag;
	startLightValue->yellow_flag = newValue;
	startLightValue->update_flag = 1;
}
/* USER CODE END 0 */

/**
  * @brief  The application entry point.
  * @retval int
  */
int main(void)
{

  /* USER CODE BEGIN 1 */
	ptr_man_capture_isr = track_data_callback;

  /* USER CODE END 1 */

  /* MCU Configuration--------------------------------------------------------*/

  /* Reset of all peripherals, Initializes the Flash interface and the Systick. */
  HAL_Init();

  /* Configure the system clock */
  SystemClock_Config();

  /* Initialize all configured peripherals */
  MX_GPIO_Init();
  MX_DMA_Init();
  MX_TIM3_Init();
  MX_TIM14_Init();
  MX_TIM16_Init();
  MX_USART1_UART_Init();
  /* USER CODE BEGIN 2 */

	// init ws2812b
	HAL_TIM_PWM_MspInit(&htim16);
	dma_status_pwm = start_lights_init(&htim16, TIM_CHANNEL_1, TIM_DIER_CC1DE);

	// init track interrupt
	//HAL_TIM_IC_Start_IT(&htim3, TIM_CHANNEL_4);
	LL_TIM_CC_EnableChannel(TIM3, LL_TIM_CHANNEL_CH4);
	LL_TIM_EnableIT_CC4(TIM3);
	LL_TIM_EnableCounter(TIM3);

	// init light behavior
	light_mode = HAL_GPIO_ReadPin(GPIOA, LIGHT_MODE_SJ_Pin) == 1 ? START_LIGHT_MODE : PIT_LANE_LIGHT_MODE;
	start_light_alignment = HAL_GPIO_ReadPin(START_LIGHT_ALIGNMENT_GPIO_Port, START_LIGHT_ALIGNMENT_Pin) == 1 ?
			ALIGNMENT_HORIZONTAL : ALIGNMENT_VERTICAL;
	session_type = HAL_GPIO_ReadPin(RACE_TRAINING_SESSION_SW_GPIO_Port, RACE_TRAINING_SESSION_SW_Pin) == 0 ? RACE : QUALIFYING_TRAINING;
	uart_race_info.session_type = session_type;

	// init track lights
	//HAL_TIM_PWM_Start(&htim14, TIM_CHANNEL_1); // red
	// Enable output
	LL_TIM_CC_EnableChannel(TIM14, LL_TIM_CHANNEL_CH1);
	// Enable counter
	LL_TIM_EnableCounter(TIM14);
	// Force update generation to apply settings
	//LL_TIM_GenerateEvent_UPDATE(TIM14);


	TIM14->CCR1 = 0;//80;
	HAL_GPIO_WritePin(TRACK_GREEN_GPIO_Port, TRACK_GREEN_Pin, GPIO_PIN_RESET);

	//HAL_UART_Receive_DMA(&huart1, uart_rx_buffer, UART_TX_BUF_LEN);

  /* USER CODE END 2 */

  /* Infinite loop */
  /* USER CODE BEGIN WHILE */
	while (1)
	{
    /* USER CODE END WHILE */

    /* USER CODE BEGIN 3 */

		// BLOCK 1 - DECODE MANCHESTER DATA
		difference_rw = circ_distance(data_manchester_circular_read_index, data_manchester_circular_index);
		if (3 < difference_rw){
			uint16_t read_to = data_manchester_circular_index;
			uint16_t read_index = data_manchester_circular_read_index;

			while (read_index != read_to){

				/*
				 * Process
				 *
				 * Filter the message of interest here
				 *
				 * For the lights we need safety car and status messages.
				 *
				 * If the safety car is released, choose this one. Otherwise we only
				 * need the status messages.
				 *
				 * Status messages
				 * 	lights should be indicated with 0x17 (and)
				 * 	jump start indicated with (((0x000F << 8) & message) == (0x001 << 11)) && ((0x000D << 4) & message)
				 *
				 * Safety car message
				 * 	indicated with 0b0000001111000000;
				 */

				if (( data_manchester[read_index].data> 512-1 ) && (data_manchester[read_index].data < 1024)){
					// car message
					if ( (data_manchester[read_index].data & (0x0007 << 6)) == (0x0007 << 6)){
						// safety car message
						if (data_manchester[read_index].data & (0x0001 << 1)){
							// safety car active - high priority message
							message_to_proceed = data_manchester[read_index].data;
						} else if (message_to_proceed == 0){
							// safety car message  - low priority message
							// necessary to detect if release was withdrawn
							message_to_proceed = data_manchester[read_index].data;
						}
					}
				} else if ((data_manchester[read_index].data > 4096-1) && (data_manchester[read_index].data < 8192)){
					// control unit message
					track_counter++; // message block repeats every 75ms

					uint16_t encode_signal = data_manchester[read_index].data;
					uint8_t controller =
							((encode_signal >> 0) & 0x01) << 2 |
							((encode_signal >> 1) & 0x01) << 1 |
							((encode_signal >> 2) & 0x01) << 0;

					uint8_t command =
							((encode_signal >> 3) & 0x01) << 4 |
							((encode_signal >> 4) & 0x01) << 3 |
							((encode_signal >> 5) & 0x01) << 2 |
							((encode_signal >> 6) & 0x01) << 1 |
							((encode_signal >> 7) & 0x01) << 0;

					uint8_t value =
							((encode_signal >> 8) & 0x01) << 3 |
							((encode_signal >> 9) & 0x01) << 2 |
							((encode_signal >> 10) & 0x01) << 1 |
							((encode_signal >> 11) & 0x01) << 0;

					if ((11 == command) && (1 == value)){
						// jump start
						message_to_proceed = data_manchester[read_index].data;
					} else if ((16 == command) && (7 == controller)){
						// start light
						message_to_proceed = data_manchester[read_index].data;
					} else {
						// catch unprocessed cu data for uart

						// unfortunately we have to go through various if statements.
						if ((6 > controller) && !(0 == command)){
							// things we never ever want to proceed
							if (4 == command){
								if (8 > value){
									// fuel level of car - 7 is full
									uart_race_info.driver_data[controller].fuel = value;
								} else if (16 > value){
									// not really neccessary. Called at jump start
									uart_race_info.driver_data[controller].fuel = value - 8;
								}
							}else if (6 == command){
								if (value < 9){
									// postition
									value--; // position -1 to fit in 4 bits
									uart_race_info.driver_data[controller].position = value;
								} else if (9 == value) {
									// reset lap counter and positions
									uart_race_info.reset_event = 1;
									uart_race_info.lap_count = 0;
									for (uint8_t _cntrl = 0; _cntrl < 6; _cntrl++){
										uart_race_info.driver_data[controller].finished = 0;
										uart_race_info.driver_data[controller].position = 0;
										uart_race_info.driver_data[controller].fuel = 0;
										uart_race_info.driver_data[controller].laps = 0;
									}
								}
							} else if (7 == command){
								// driver finishes race
								uart_race_info.driver_data[controller].finished = 1;
							} else if (8 == command){
								// driver finishes lap / race with new fastest lap
								uart_race_info.fastest_lap_driver = controller;
								uart_race_info.driver_data[controller].laps++;
							} else if (9 == command){
								// driver finishes lap / race wiout new fastest lap
								uart_race_info.driver_data[controller].laps++;
							} else if ((10 == command) && (8 > value)){
								// fuel level of car - 7 is full
								uart_race_info.driver_data[controller].fuel = value;
							}
						} else if ((17 == command) && (7 == controller)){
							// first nibble lap count leader
							uart_race_info.lap_count = value << 4;
							uart_race_info.lap_count_nibble_completed = 0;
						} else if ((18 == command) && (7 == controller)){
							// first nibble lap count leader
							uart_race_info.lap_count |= value;
							uart_race_info.lap_count_nibble_completed = 1;
						}
					} // catch unprocessed cu data for uart end
				} // control unit message end

				if (message_to_proceed > 0)
					track_data_available = 1;

				read_index = circ_next(read_index); // ends with actual write index
			}
			data_manchester_circular_read_index = read_index;
		}

		// BLOCK 2 - PROCESS ALTERNATING PROCESSES

		/*
		 * Use control unit message interval as clock (kind of synchronization pulse)
		 * for time based alterations at the lights. This is necessary when
		 * more then one controller controls different lights on the track
		 * to avoid drift in blinks.
		 *
		 * The increment frequency is 13.3 Hz (75ms)
		 */
		millis_sync_state_change_flag = millis_sync_prev != track_counter ? 1 : 0;
		millis_sync_prev = track_counter;

		// do some stuff with 1.3 Hz (750ms)
		if ((9 < track_counter - uart_tx_last_transmit) && (1 == millis_sync_state_change_flag)){
			/*
			 * Read Race State
			 */
			session_type = HAL_GPIO_ReadPin(RACE_TRAINING_SESSION_SW_GPIO_Port, RACE_TRAINING_SESSION_SW_Pin) == 0 ? RACE : QUALIFYING_TRAINING;
			uart_race_info.session_type = session_type;


			/*
			 * Transmit race state info
			 */
			uint8_t write_index = 0;
			for (uint8_t _driver = 0; _driver < 6; _driver++){
				uart_tx_buffer[write_index++] = 0x00 | uart_race_info.driver_data[_driver].position;
				uart_tx_buffer[write_index++] = 0x00 | uart_race_info.driver_data[_driver].fuel;
				uart_tx_buffer[write_index++] = 0x00 | uart_race_info.driver_data[_driver].laps;
				uart_tx_buffer[write_index++] = 0x00 | uart_race_info.driver_data[_driver].finished;
			}

			uart_tx_buffer[write_index++] = 0x00 | uart_race_info.fastest_lap_driver;
			uart_tx_buffer[write_index++] = 0x00 | uart_race_info.start_lights;
			uart_tx_buffer[write_index++] = 0x00 | uart_race_info.lap_count;
			uart_tx_buffer[write_index++] = 0x00 | uart_race_info.reset_event;
			uart_tx_buffer[write_index++] = 0x00 | uart_race_info.race_state;
			uart_tx_buffer[write_index++] = 0x00 | uart_race_info.session_type;

			uart_tx_buffer[write_index++] = (0xFF00 & track_counter) >> 8;
			uart_tx_buffer[write_index++] = (0x00FF & track_counter);


			LL_DMA_DisableChannel(DMA1, LL_DMA_CHANNEL_2);
			LL_DMA_EnableIT_TC(DMA1, LL_DMA_CHANNEL_2); // RX complete interrupt
			LL_DMA_EnableChannel(DMA1, LL_DMA_CHANNEL_2);

			// reset track reset event
			uart_race_info.reset_event = 0;
		}

		// BLOCK 3 - PROCESS THE MESSAGES THAT CONTROLS THE LIGHTS

		/*
		 * Process the messages
		 *
		 * Assumption is, that the execution interval is smaller than 75ms.
		 * This is the time until the next message block will be sent by the control unit.
		 *
		 * If this is the case, only one message contains data of interest.
		 * A really unlikely case is, when the safety car button will be pressed in the same
		 * message block the starting lights went off. But this is almost impossible due to
		 * bufferical limits. Try it, but you have round about 6.5ms to engage safety car key
		 * after the start lights went off ;)
		 *
		 */
		if (track_data_available == 1){
			track_data_available = 0;

			// decode cu message
			CuMessage decoded_data = decode_manchester(message_to_proceed);
			message_to_proceed = 0;

			// set start light instantly
			if (CU_START_LIGHT == decoded_data.type){
				update_start_light_value_red(&start_light_value, decoded_data.value);

				if (decoded_data.value == 5 ){
					if (race_state.curr != RACE_STATE_START_PROC) // if start proc then it relates to it
						update_race_state(&race_state, RACE_STATE_RED_FLAG);
				} else if (decoded_data.value == 1) //
					update_race_state(&race_state, RACE_STATE_START_PROC);
				else if (decoded_data.value == 0) {
					if  ((race_state.curr == RACE_STATE_START_PROC) && race_state.prev == RACE_STATE_RED_FLAG){
						start_light_change_time = track_counter;
					}
					else if (race_state.curr == RACE_STATE_RED_FLAG){
						update_race_state(&race_state, RACE_STATE_GREEN_FLAG);
						green_flag_triggered_time = track_counter;
					}
				}
			}

			if (RACE_STATE_START_PROC == race_state.curr){
				if (!start_light_value.red_count && (track_counter - start_light_change_time > 6)){ // (!start_light_value.red_count && (millis - start_light_change_time > 400))
					update_race_state(&race_state, RACE_STATE_OPEN);
					if ((PIT_LANE_LIGHT_MODE == light_mode) || (QUALIFYING_TRAINING == session_type))
						start_light_value.update_flag = 1;
				}
			}

			if (CU_CONTROLLER_JUMPSTART == decoded_data.type){
				update_race_state(&race_state, RACE_STATE_JUMP_START);
			}


			// check for yellow flag
			if (CU_CONTROLLER_SAFETY_CAR == decoded_data.type){
				if (decoded_data.value && (race_state.curr != RACE_STATE_YELLOW_FLAG))
					safetycar_debounce++;

				if (!decoded_data.value && (race_state.curr == RACE_STATE_YELLOW_FLAG))
					safetycar_debounce--;

				if ((1 < safetycar_debounce) && (race_state.curr != RACE_STATE_YELLOW_FLAG))
					update_race_state(&race_state, RACE_STATE_YELLOW_FLAG);

				if ((safetycar_debounce == 0) && (race_state.curr == RACE_STATE_YELLOW_FLAG)){
					update_race_state(&race_state, RACE_STATE_GREEN_FLAG);
					green_flag_triggered_time = track_counter;
				}
			}
		}


		/*
		 * Update the lights and update race state if required (green flag)
		 */

		// start light value changed
		if (start_light_value.red_count != start_light_value.red_count_prev)
			update_start_light_value_red(&start_light_value, start_light_value.red_count);

		// SAFETY CAR
		if (RACE_STATE_YELLOW_FLAG == race_state.curr){
			if (track_counter - safetycar_flash_interval > 3){ // (millis - safetycar_flash_interval > 200){
				safetycar_flash_interval = track_counter;
				if (0 == start_light_value.yellow_flag)
					update_start_light_value_yellow(&start_light_value, 1);
				else
					update_start_light_value_yellow(&start_light_value, 0);
			}
		} else {
			if (start_light_value.yellow_flag && (RACE_STATE_JUMP_START != race_state.curr)){
				update_start_light_value_yellow(&start_light_value, 0);
				update_start_light_value_yellow(&start_light_value, 0);
			}
		}

		// green flag
		if (RACE_STATE_GREEN_FLAG == race_state.curr){
			if (track_counter - green_flag_millis_flash > 7){ // (millis - green_flag_millis_flash > 500)
				if (!start_light_value.green_flag){
					green_flag_millis_flash = track_counter;
					update_start_light_value_green(&start_light_value, 1);
				}else {
					green_flag_millis_flash = track_counter;
					update_start_light_value_green(&start_light_value, 0);
				}
			}

			if (track_counter - green_flag_triggered_time > 142) //millis - green_flag_triggered_time > 10000
				update_race_state(&race_state, RACE_STATE_OPEN);
		}else{
			if ((1 == start_light_value.green_flag) && (RACE == session_type))
				update_start_light_value_green(&start_light_value, 0);
			else if ((0 == start_light_value.green_flag) && (QUALIFYING_TRAINING == session_type) && (RACE_STATE_OPEN == race_state.curr))
				update_start_light_value_green(&start_light_value, 1);
			else if ((1 == start_light_value.green_flag) && (QUALIFYING_TRAINING == session_type) && (RACE_STATE_OPEN != race_state.curr))
				update_start_light_value_green(&start_light_value, 0);
		}


		// JUMP START
		if (RACE_STATE_JUMP_START == race_state.curr){
			if (track_counter - jump_start_millis_flash > 7){ //(millis - jump_start_millis_flash > 500)
				jump_start_millis_flash = track_counter;
				update_start_light_value_red(&start_light_value, 5);
				if (!start_light_value.yellow_flag)
					update_start_light_value_yellow(&start_light_value, 1);
				else
					update_start_light_value_yellow(&start_light_value, 0);
			}
		}

		// BLOCK 4 - SET THE LIGHS

		/*
		 * state changes come with changes to the traffic lights
		 */
		if (start_light_value.update_flag){
			start_light_value.update_flag = 0;

			/*
			 * SET TRACK LIGHTS
			 */
			uint16_t track_light_green = 0;
			uint16_t track_light_red = 0;

			if (race_state.curr == RACE_STATE_RED_FLAG)
				track_light_red = 100;

			if (race_state.curr == RACE_STATE_YELLOW_FLAG)
				if (start_light_value.yellow_flag){
					track_light_green = 1;
					track_light_red = 66;
				}

			if (start_light_value.green_flag)
				track_light_green = 1;

			if (track_light_green)
				HAL_GPIO_WritePin(TRACK_GREEN_GPIO_Port, TRACK_GREEN_Pin, GPIO_PIN_SET);
			else
				HAL_GPIO_WritePin(TRACK_GREEN_GPIO_Port, TRACK_GREEN_Pin, GPIO_PIN_RESET);
			TIM14->CCR1 = track_light_red;
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

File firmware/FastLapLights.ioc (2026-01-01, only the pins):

Mcu.UserName=STM32C011F4Px
PA0.Signal=S_TIM16_CH1
PA1.GPIO_Label=START_LIGHT_ALIGNMENT
PA1.Signal=GPIO_Input
PA13.Signal=DEBUG_SWDIO
PA14-BOOT0.Signal=DEBUG_SWCLK
PA3.GPIO_Label=RACE_TRAINING_SESSION_SW
PA3.Signal=GPIO_Input
PA6.GPIO_Label=TRACK_GREEN
PA6.Signal=GPIO_Output
PA7.GPIO_Label=TRACK_RED_PWM
PA7.Signal=S_TIM14_CH1
PA8.GPIO_Label=IO_POWER_RAIL_DATA_FALL
PA8.Signal=S_TIM3_CH4
PB7.Signal=USART1_RX

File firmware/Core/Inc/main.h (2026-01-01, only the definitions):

#define START_LIGHT_ALIGNMENT_Pin GPIO_PIN_1
#define START_LIGHT_ALIGNMENT_GPIO_Port GPIOA
#define RACE_TRAINING_SESSION_SW_Pin GPIO_PIN_3
#define RACE_TRAINING_SESSION_SW_GPIO_Port GPIOA
#define TRACK_GREEN_Pin GPIO_PIN_6
#define TRACK_GREEN_GPIO_Port GPIOA
#define TRACK_RED_PWM_Pin GPIO_PIN_7
#define TRACK_RED_PWM_GPIO_Port GPIOA
#define IO_POWER_RAIL_DATA_FALL_Pin GPIO_PIN_8
#define IO_POWER_RAIL_DATA_FALL_GPIO_Port GPIOA
#define LIGHT_MODE_SJ_Pin GPIO_PIN_12
#define LIGHT_MODE_SJ_GPIO_Port GPIOA

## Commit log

2025-03-28 add pcb mk4 remake
    [A768KS227M1VLAE024.step, DV-T263-201E-TR.stp, FastLapLights.kicad_pcb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]
2025-03-28 assembly files
    [FastLapLights-BOM.csv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]
2025-03-28 add grb
    [FastLapLights-B_Cu.gbr, FastLapLights-B_Mask.gbr, FastLapLights-B_Paste.gbr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]
2025-03-28 update footprint
    [FastLapLights.kicad_pcb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]
2025-04-02 prep firmware
    [FastLapLights.kicad_pcb, FastLapLights.kicad_sch]
2025-04-03 migrate ws2812b and manchester decoder
    [FastLapLights.kicad_pcb]
2025-04-04 tried to fix stubborn hal
    [ws2812b_start_lights.c]
2025-04-05 fix bad behavior of first led - omg what a hair-raising solution. Let the dma catch breath before sending the first bit
    [ws2812b_start_lights.c]
2025-04-07 migrate track lights
    [FastLapLights.kicad_pcb, FastLapLights.kicad_sch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]
2025-04-13 add 5V version
    [74HCT1G125GV,125.stp, A768KS227M1VLAE024.step, DR1030-220-R.stp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]
2025-04-14 change jlcpcb parts
    [FastLapLights-BOM.csv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]
2025-04-14 change sj start light - pit lane light
    [FastLapLights-BOM.csv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]
2025-05-14 fix issues with decoding manchester data and make it more reliable
    [FastLapLights5V-B_Cu.gbr, FastLapLights5V-B_Mask.gbr, FastLapLights5V-B_Paste.gbr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]
2025-05-15 activate solder jumper pin, replace sold-out components
    [A768KS227M1VLAE024.step, DV-T263-201E-TR.stp, FastLapLights-BOM.csv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]
2025-06-11 - add race mode practice session - i2c to uart for faster datastreaming to displays - fix timer issue with tim1
    [FastLapLights5V.kicad_pcb, FastLapLights5V.kicad_sch]
2025-07-16 add wiring
2025-10-13 - save some spave with ll driver - rewrite data link layer :cq git commit -m
2026-01-10 fix workaround
    [FastLapLights5V-B_Cu.gbr, FastLapLights5V-B_Mask.gbr, FastLapLights5V-B_Paste.gbr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]

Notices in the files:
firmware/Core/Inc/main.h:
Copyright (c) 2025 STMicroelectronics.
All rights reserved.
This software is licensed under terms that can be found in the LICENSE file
